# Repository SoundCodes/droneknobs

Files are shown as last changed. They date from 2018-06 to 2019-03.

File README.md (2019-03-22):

# droneknobs
#### Knobs that make Drone

Its a Synth made during [KYTA 2017](https://issuu.com/shazeb/docs/kyta_2017_catalog) at Kalga as part of Residency for a new [notional experimental quadraphonic audio environment](https://sound.codes/works/kyta-karma-quad/) in the Himalayas. 
droneknobs

The facility will be open to experimental sound artists from the summer of 2018 as a making,  listening and hacking space. 
Check the making and the story behind this on [youtube](https://www.youtube.com/watch?v=MHGiTG6djZ0)

>  *Modified slightly the code by Tim Barrass using Mozzi library*

This built demonstrates analog inputs from 16 channel multiplexer [«CD74HC4067»](https://github.com/pAIgn10/MUX74HC4067) and control oscillators, phase modulation and smoothing a control signal at audio rate. Also demonstrates AutoMap, which maps unpredictable inputs to a set range.
 
  ## The circuit:
##### Leonardo :
     Audio output on digital pin 9 (on a Uno, Leonardo and Nano), or
     Potentiometers on A1 A2 A3 A4 A5 A6 A7 A8 A10 A11 on Leonardo
     MUX74HC4067:
	 Signal conects to A0
     EN pin connects to 13
     S0 » 11, S1 » 7, S2 » 5, S3 » 3
     Potentiometers on 0-9
	 
##### Nano:
	 Audio output on digital pin 9
	 Potentiometers on A1 A2 A3 A4 A5 A6 A7
	 MUX74HC4067:
	 ignal conects to A0
     EN pin connects to 13
     S0 » 11, S1 » 7, S2 » 5, S3 » 3
     Potentiometers on 0-9
	 
##### UNO:
	 Audio output on digital pin 9
	 Potentiometers on A1 A2 A3 A4 A5 
	 MUX74HC4067:
	 Signal conects to A0
     EN pin connects to 13
     S0 » 11, S1 » 7, S2 » 5, S3 » 3
     Potentiometers on 0-9

###### Dependencies 
> [Mozzi](http://sensorium.github.com/Mozzi/)
> [CD74HC4067](https://github.com/pAIgn10/MUX74HC4067)

This Panel of Knobs enables oscillators and the control modulation. 

> Cosine wave table is used and the freq range is 8hz to 8184hz
> While the control-modulation is 0 - 127

Use this Code in Various permutation changing the analog input for oscillators and control modulators.
3 Nano + Mux, 3 Leonardo + 2 Mux and One Uno along is being used in the Panel.

Only One Leonardo is sufficient for the design with Mux used as input for mux and get all the potentiometers into one Leonardo. Doing that was making the control oscillations clicky and buggy as ATmega32u4 is not able to process 50+ simultaneous oscillators.

[Panel.dxf](https://github.com/SoundCodes/droneknobs/blob/master/panel.dxf) can be used to replicate the design using Laser or CNC.

#### ~~~~~~~~~~~~~~~~~~~~~~~~~~~~~~~~~~~~~

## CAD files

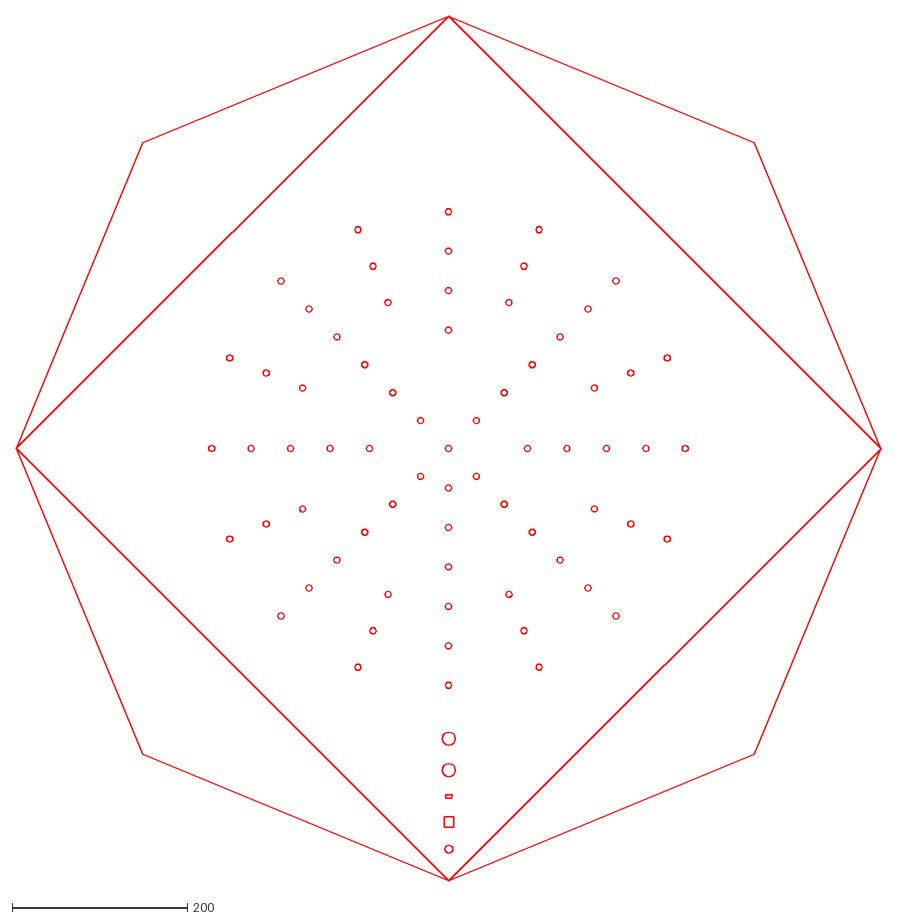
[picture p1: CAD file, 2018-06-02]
lasercut_template/panel.dxf
986.3 x 986.3

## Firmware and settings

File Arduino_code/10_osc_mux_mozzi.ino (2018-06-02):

/**
 * This example demonstrates how to read analog signals
 * It assumes there are potentiometers connected
 * to the 16 channels of the 74HC4067 mux/demux
 * 
 * For more about the interface of the library go to
 * https://github.com/pAIgn10/MUX74HC4067
 * 
 *     Analog Inputs: A0-A5, A6 - A11 (on digital pins 4, 6, 8, 9, 10, and 12). 
 *     
 *     A0  A1  A2  A3  A4  A5  A6  A7  A8  A9  A10  A11
 *     0   1   2   3    4   5:  4   6   8  9    10   12
 *     
 *     A0- A5
 *     A6 A7 A8 A10 A11
 *     
  
 */

//#include "MUX74HC4067.h"
#include <MozziGuts.h>
#include <Oscil.h>
#include <tables/cos8192_int8.h>
#include <mozzi_midi.h>

// Creates a MUX74HC4067 instance
// 1st argument is the Arduino PIN to which the EN pin connects
// 2nd-5th arguments are the Arduino PINs to which the S0-S3 pins connect
//MUX74HC4067 mux(13, 11, 7, 5, 3);
#define CONTROL_RATE 128

// harmonics
Oscil<COS8192_NUM_CELLS, AUDIO_RATE> aCos1(COS8192_DATA);
Oscil<COS8192_NUM_CELLS, AUDIO_RATE> aCos2(COS8192_DATA);
Oscil<COS8192_NUM_CELLS, AUDIO_RATE> aCos3(COS8192_DATA);
Oscil<COS8192_NUM_CELLS, AUDIO_RATE> aCos4(COS8192_DATA);
Oscil<COS8192_NUM_CELLS, AUDIO_RATE> aCos5(COS8192_DATA);
Oscil<COS8192_NUM_CELLS, AUDIO_RATE> aCos6(COS8192_DATA);
Oscil<COS8192_NUM_CELLS, AUDIO_RATE> aCos7(COS8192_DATA);
Oscil<COS8192_NUM_CELLS, AUDIO_RATE> aCos8(COS8192_DATA);

Oscil<COS8192_NUM_CELLS, AUDIO_RATE> aCos9(COS8192_DATA);
Oscil<COS8192_NUM_CELLS, AUDIO_RATE> aCos10(COS8192_DATA);
//Oscil<COS8192_NUM_CELLS, AUDIO_RATE> aCos11(COS8192_DATA);
//Oscil<COS8192_NUM_CELLS, AUDIO_RATE> aCos12(COS8192_DATA);
//Oscil<COS8192_NUM_CELLS, AUDIO_RATE> aCos13(COS8192_DATA);
//Oscil<COS8192_NUM_CELLS, AUDIO_RATE> aCos14(COS8192_DATA);
//Oscil<COS8192_NUM_CELLS, AUDIO_RATE> aCos15(COS8192_DATA);
//Oscil<COS8192_NUM_CELLS, AUDIO_RATE> aCos16(COS8192_DATA);


// volume controls
Oscil<COS8192_NUM_CELLS, CONTROL_RATE> kVol1(COS8192_DATA);
Oscil<COS8192_NUM_CELLS, CONTROL_RATE> kVol2(COS8192_DATA);
Oscil<COS8192_NUM_CELLS, CONTROL_RATE> kVol3(COS8192_DATA);
Oscil<COS8192_NUM_CELLS, CONTROL_RATE> kVol4(COS8192_DATA);
Oscil<COS8192_NUM_CELLS, CONTROL_RATE> kVol5(COS8192_DATA);
Oscil<COS8192_NUM_CELLS, CONTROL_RATE> kVol6(COS8192_DATA);
Oscil<COS8192_NUM_CELLS, CONTROL_RATE> kVol7(COS8192_DATA);
Oscil<COS8192_NUM_CELLS, CONTROL_RATE> kVol8(COS8192_DATA);

Oscil<COS8192_NUM_CELLS, CONTROL_RATE> kVol9(COS8192_DATA);
Oscil<COS8192_NUM_CELLS, CONTROL_RATE> kVol10(COS8192_DATA);
//Oscil<COS8192_NUM_CELLS, CONTROL_RATE> kVol11(COS8192_DATA);
//Oscil<COS8192_NUM_CELLS, CONTROL_RATE> kVol12(COS8192_DATA);
//Oscil<COS8192_NUM_CELLS, CONTROL_RATE> kVol13(COS8192_DATA);
//Oscil<COS8192_NUM_CELLS, CONTROL_RATE> kVol14(COS8192_DATA);
//Oscil<COS8192_NUM_CELLS, CONTROL_RATE> kVol15(COS8192_DATA);
//Oscil<COS8192_NUM_CELLS, CONTROL_RATE> kVol16(COS8192_DATA);

// audio volumes updated each control interrupt and reused in audio till next control
char v1,v2,v3,v4,v5,v6,v7,v8,v9,v10;


void setup()
{
	Serial.begin(9600);  // Initializes serial port
    // Waits for serial port to connect. Needed for Leonardo only
    while ( !Serial ) ;
	
	// Configures how the SIG pin will be interfaced
	// e.g. The SIG pin connects to PIN A0 on the Arduino,
	//      and PIN A0 is a analog input
//	mux.signalPin(A0, INPUT, ANALOG);
 
  // set harmonic frequencies
  aCos1.setFreq(mtof(60));
  aCos2.setFreq(mtof(74));
  aCos3.setFreq(mtof(64));
  aCos4.setFreq(mtof(77));
  aCos5.setFreq(mtof(67));
  aCos6.setFreq(mtof(81));
  aCos7.setFreq(mtof(60));
  aCos8.setFreq(mtof(75));
  aCos9.setFreq(mtof(75));
  aCos10.setFreq(mtof(72));
//  aCos11.setFreq(mtof(74));
//  aCos12.setFreq(mtof(65));
//  aCos13.setFreq(mtof(55));
//  aCos14.setFreq(mtof(85));
//  aCos15.setFreq(mtof(78));
//  aCos16.setFreq(mtof(64));
//  aCrunchySound.setFreq(100);

// set volume change frequencies
  kVol1.setFreq(4.43f); // more of a pulse
  kVol2.setFreq(0.0245f);
  kVol3.setFreq(0.019f);
  kVol4.setFreq(0.07f);
  kVol5.setFreq(0.047f);
  kVol6.setFreq(0.031f);
  kVol7.setFreq(0.0717f);
  kVol8.setFreq(0.041f);
  kVol9.setFreq(4.43f); // more of a pulse
  kVol10.setFreq(0.0245f);
//  kVol11.setFreq(0.019f);
//  kVol12.setFreq(0.07f);
//  kVol13.setFreq(0.047f);
//  kVol14.setFreq(0.031f);
//  kVol15.setFreq(0.0717f);
//  kVol16.setFreq(0.041f);

  v1=v2=v3=v4=v5=v6=v7=v8=v9=v10=127; //=v6=v7=v8=v9=v10=v11=v12=v13=v14=v15=v16
  
  startMozzi(CONTROL_RATE);
 
}

// Reads the 16 channels and reports on the serial monitor
// the corresponding value read by the A/D converter
void loop()
{
	int data;

	for (byte i = 0; i < 5; ++i)
	{
		// Reads from channel i. Returns a value from 0 to 1023
		data = mux.read(i);
	}


    audioHook();

	delay(10);
}

void updateControl(){
   //*     A6 A7 A8 A10 A11   
    
  aCos1.setFreq((mozziAnalogRead(A1)*8));
  aCos2.setFreq((mozziAnalogRead(A2)*8));
  aCos3.setFreq((mozziAnalogRead(A3)*8));
  aCos4.setFreq((mozziAnalogRead(A4)*8));
  aCos5.setFreq((mozziAnalogRead(A5)*8));
  aCos6.setFreq((mozziAnalogRead(A6)*8));
  aCos7.setFreq((mozziAnalogRead(A7)*8));
  aCos8.setFreq((mozziAnalogRead(A8)*8));
  aCos9.setFreq((mozziAnalogRead(A10)*8));
  aCos10.setFreq((mozziAnalogRead(A11)*8));
   v1 = mux.read(0)/12; // going at a higher freq, this creates zipper noise, so reduce the gain
   v2 = mux.read(1)/12;
   v3 = mux.read(2)/12;
   v4 = mux.read(3)/12;
   v5 = mux.read(4)/12;
   v6 = mux.read(5)/12;
   v7 = mux.read(6)/12;
   v8 = mux.read(7)/12;
   v9 = mux.read(8)/12;
   v10 = mux.read(9)/12;
}

int updateAudio(){
  long asig = (long)
    aCos1.next()*v1 +
    aCos2.next()*v2 +
    aCos3.next()*v3 +
    aCos4.next()*v4 +
    aCos5.next()*v5 +
    aCos6.next()*v6 +
    aCos7.next()*v7 +
    aCos8.next()*v8 +
    aCos9.next()*v9 +
    aCos10.next()*v10 ;
//    aCos11.next()*v11 +
//    aCos12.next()*v12 +
//    aCos13.next()*v13 +
//    aCos14.next()*v14 +
//    aCos15.next()*v15 +
//    aCos16.next()*v16;
  asig >>= 11;
  return (int) asig;
}

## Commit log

2018-06-02 Add files via upload
    Laser Cut Steel Panel
    [panel.dxf]
2018-06-02 Create Laser Cut Template
